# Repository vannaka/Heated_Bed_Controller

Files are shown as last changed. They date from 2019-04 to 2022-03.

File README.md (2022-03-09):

Heated_Bed_Controller

# PCB Images
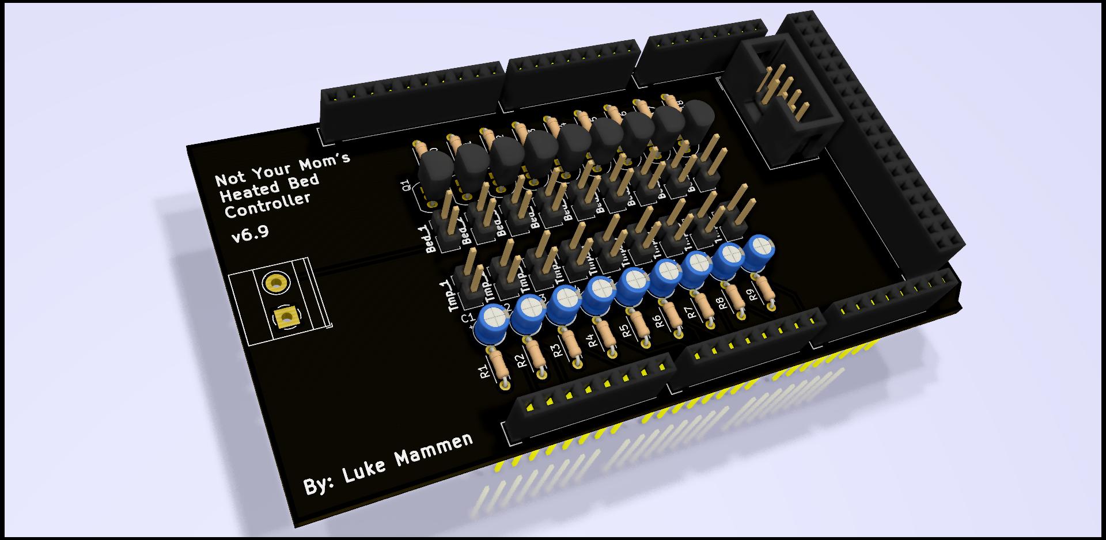
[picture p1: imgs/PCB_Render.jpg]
PCB Render

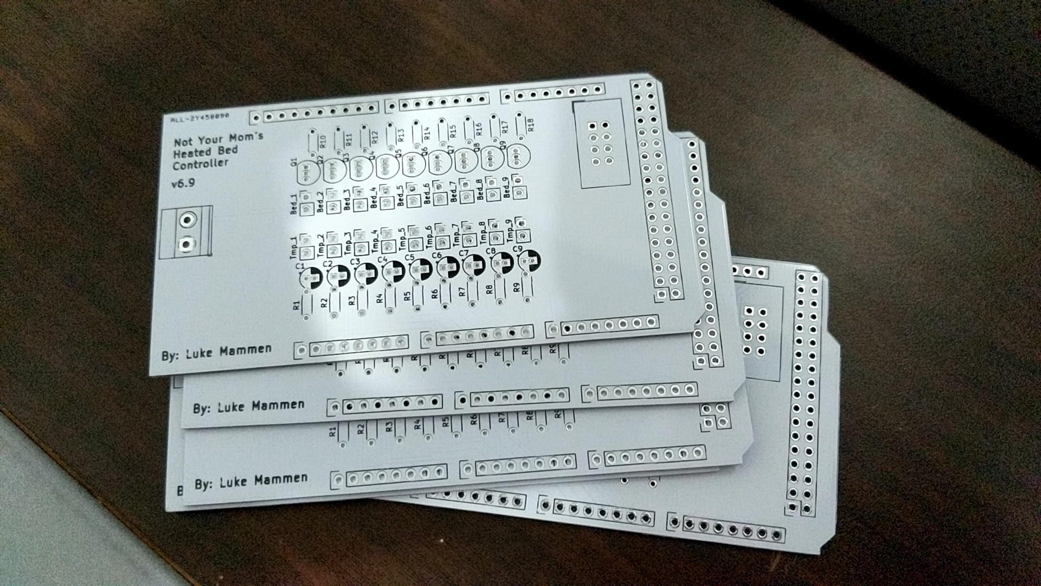
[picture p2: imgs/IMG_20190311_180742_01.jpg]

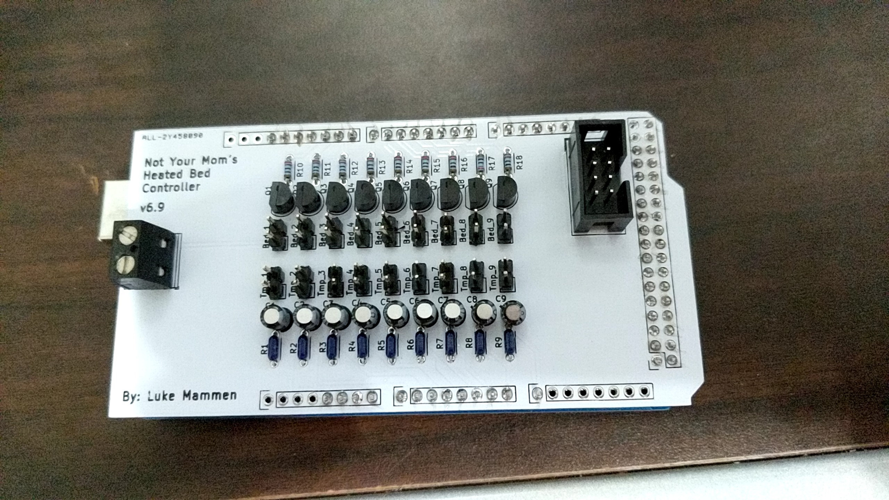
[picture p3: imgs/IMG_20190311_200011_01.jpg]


# Prototyping
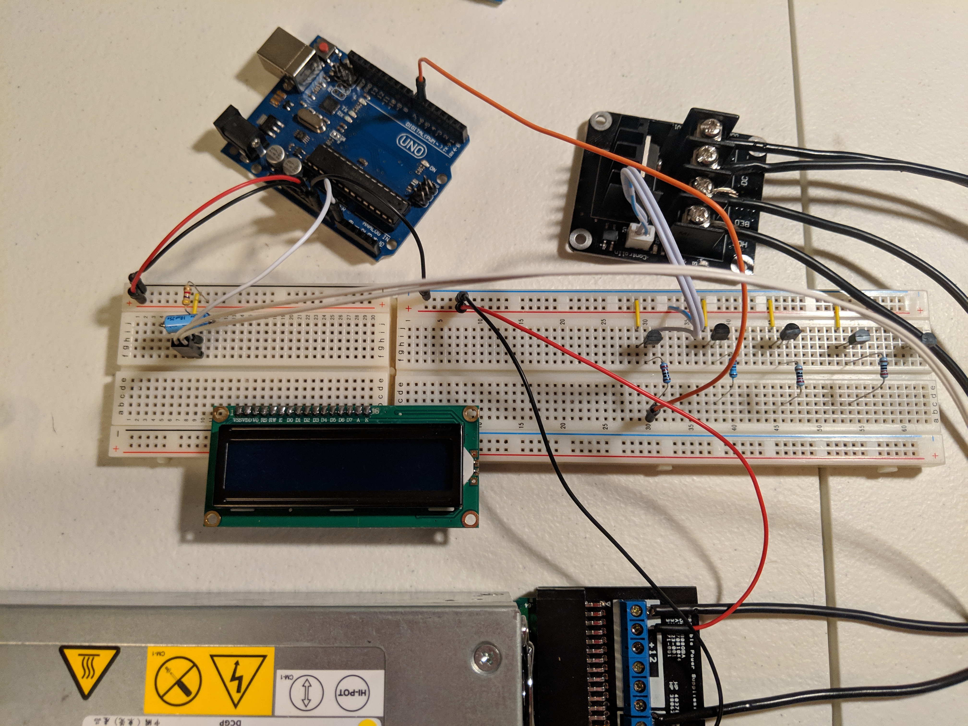
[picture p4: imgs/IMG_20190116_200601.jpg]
Breadboard

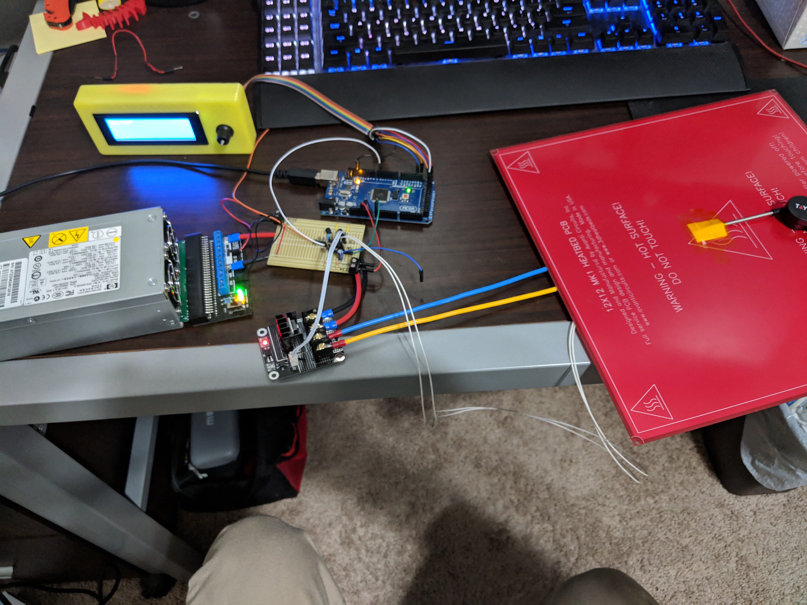
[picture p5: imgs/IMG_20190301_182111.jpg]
Protoboard


# Screen & Nob
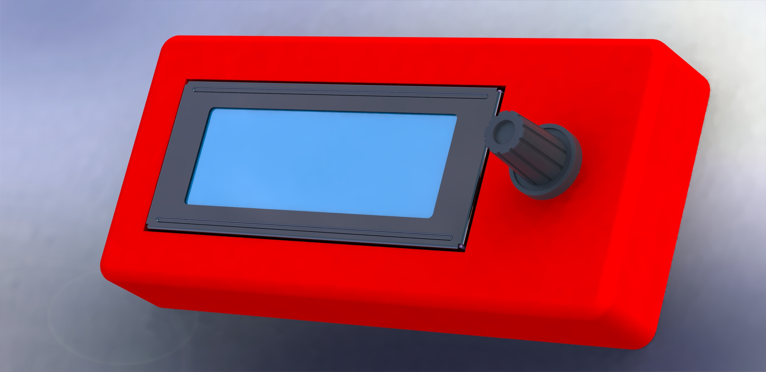
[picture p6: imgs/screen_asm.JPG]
Screen_render

Screen_test
Screen_final

# Wiring
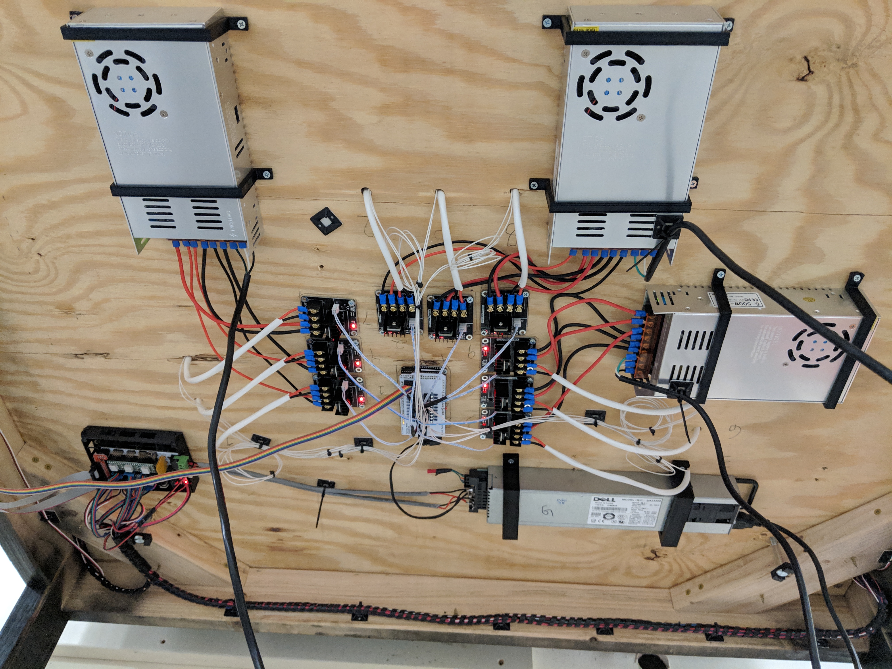
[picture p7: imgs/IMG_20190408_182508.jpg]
Wiring


# Bed & Printer
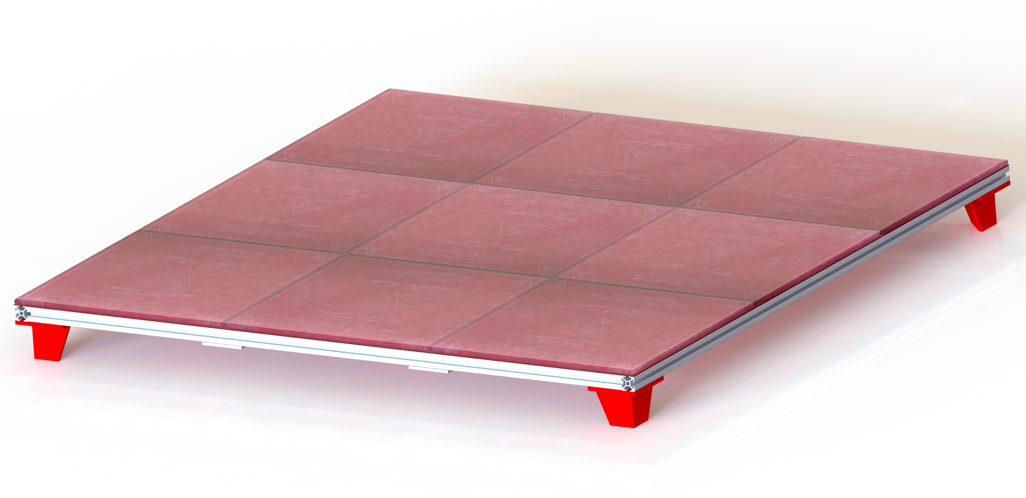
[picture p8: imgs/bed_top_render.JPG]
Bed_render

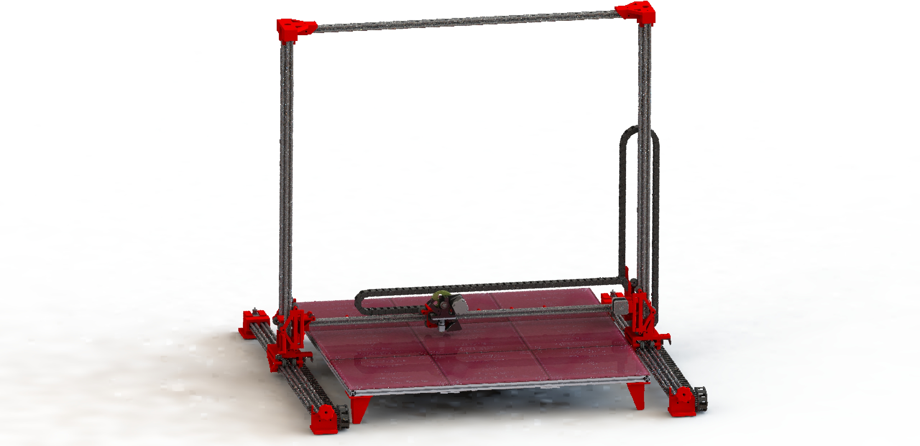
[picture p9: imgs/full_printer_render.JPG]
Full_printer_render

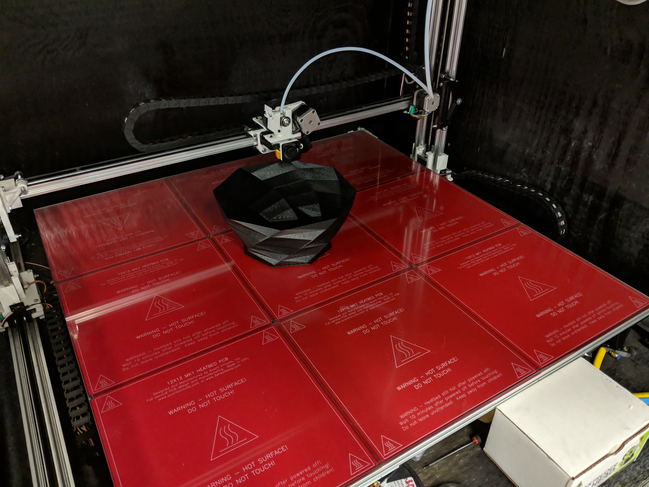
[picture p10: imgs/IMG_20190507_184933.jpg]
vase_mid_print

vase_done

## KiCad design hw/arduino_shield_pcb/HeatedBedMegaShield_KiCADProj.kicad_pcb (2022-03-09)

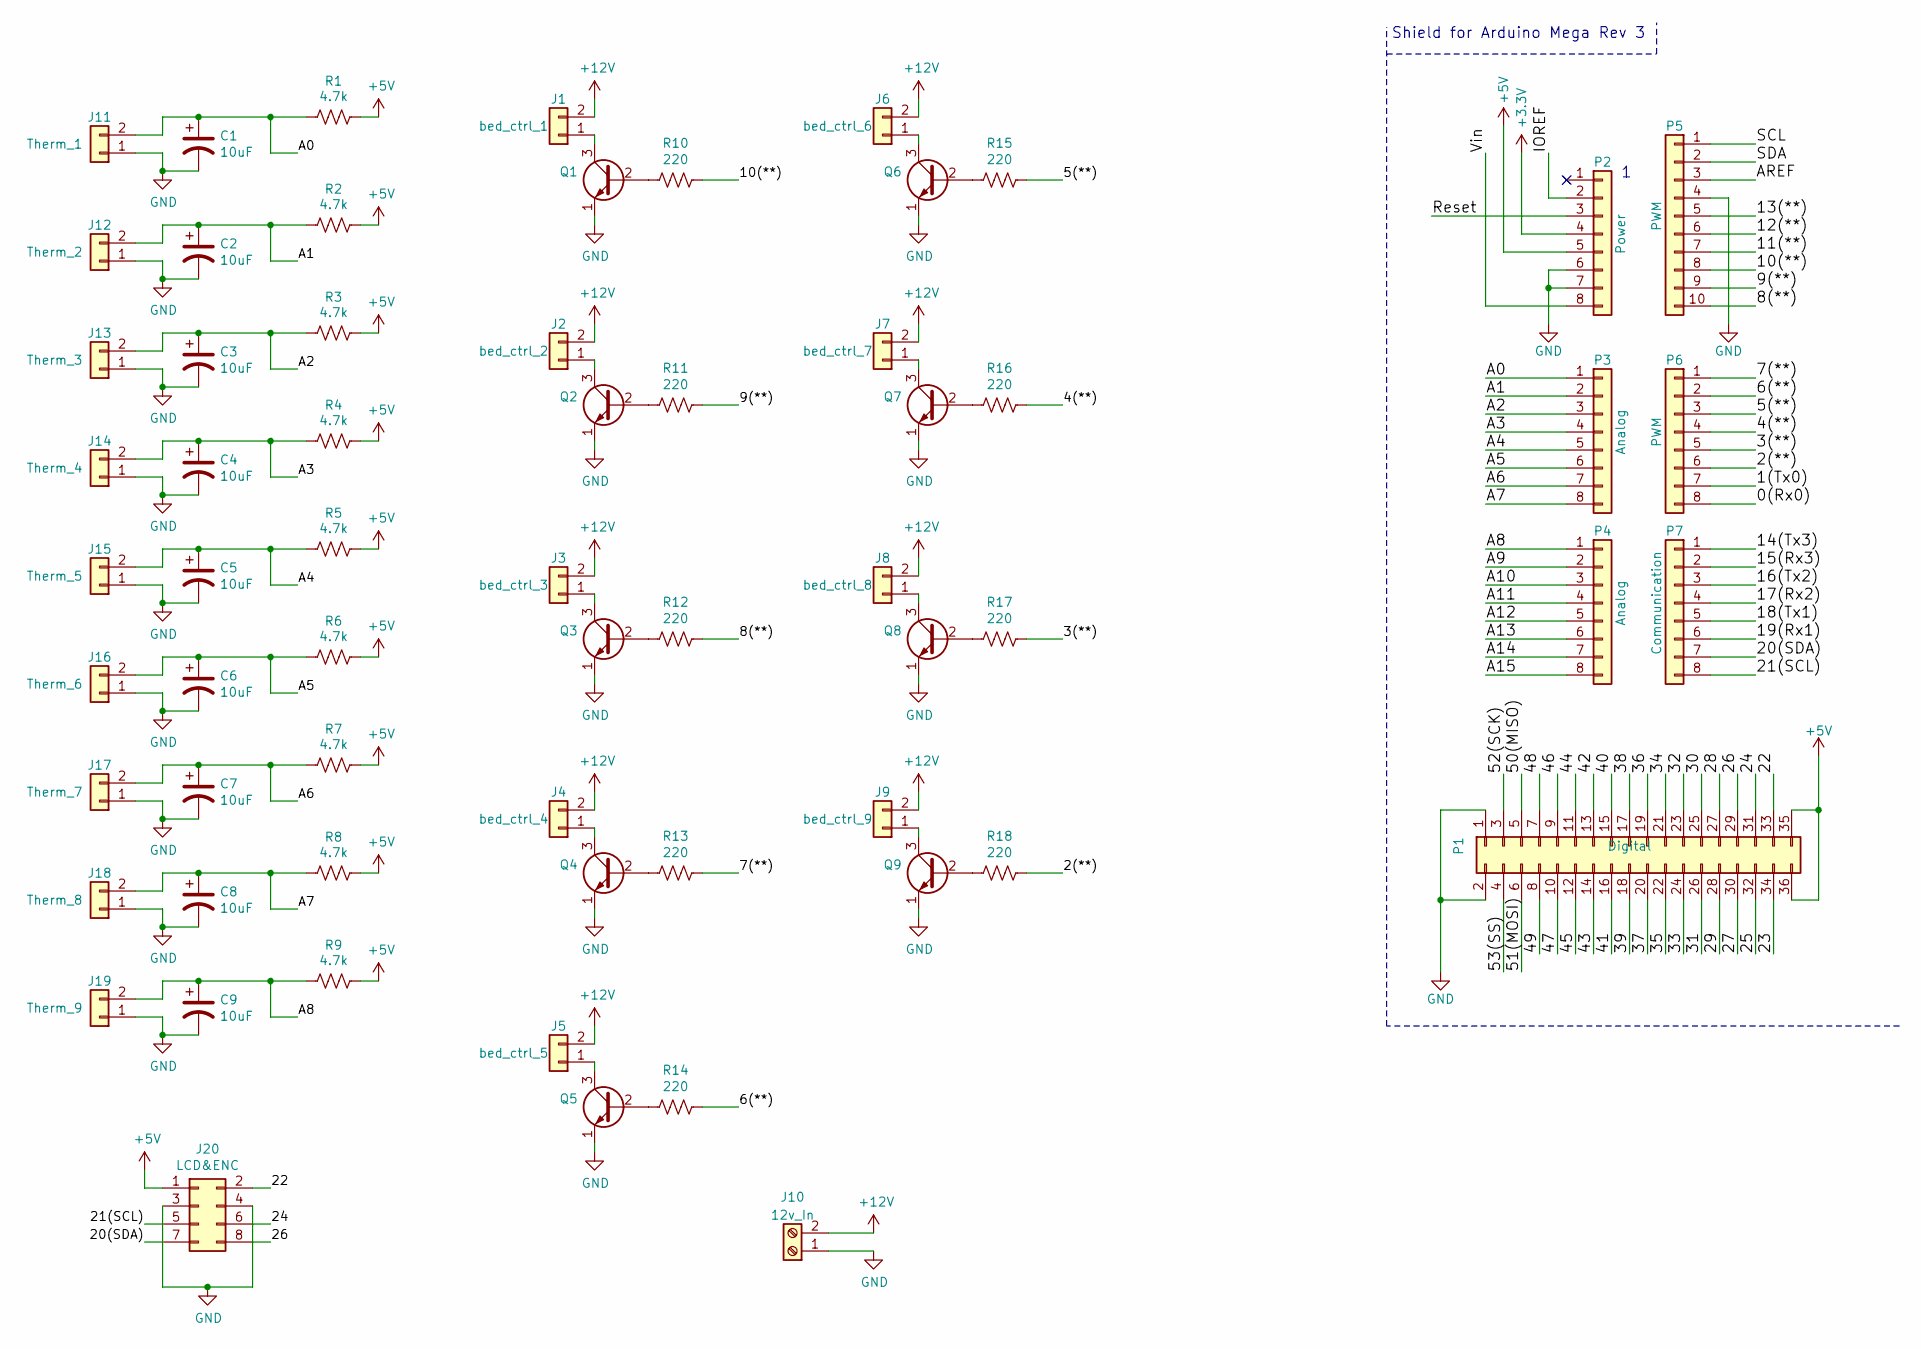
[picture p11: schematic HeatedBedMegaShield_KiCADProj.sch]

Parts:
C1, C2, C3, C4, C5, C6, C7, C8, C9: 10uF; CP_Radial_D4.0mm_P1.50mm
J1: bed_ctrl_1; PinHeader_1x02_P2.54mm_Vertical
J2: bed_ctrl_2; PinHeader_1x02_P2.54mm_Vertical
J3: bed_ctrl_3; PinHeader_1x02_P2.54mm_Vertical
J4: bed_ctrl_4; PinHeader_1x02_P2.54mm_Vertical
J5: bed_ctrl_5; PinHeader_1x02_P2.54mm_Vertical
J6: bed_ctrl_6; PinHeader_1x02_P2.54mm_Vertical
J7: bed_ctrl_7; PinHeader_1x02_P2.54mm_Vertical
J8: bed_ctrl_8; PinHeader_1x02_P2.54mm_Vertical
J9: bed_ctrl_9; PinHeader_1x02_P2.54mm_Vertical
J10: 12v_In; TerminalBlock_Phoenix_MKDS-1,5-2_1x02_P5.00mm_Horizontal
J11: Therm_1; PinHeader_1x02_P2.54mm_Vertical
J12: Therm_2; PinHeader_1x02_P2.54mm_Vertical
J13: Therm_3; PinHeader_1x02_P2.54mm_Vertical
J14: Therm_4; PinHeader_1x02_P2.54mm_Vertical
J15: Therm_5; PinHeader_1x02_P2.54mm_Vertical
J16: Therm_6; PinHeader_1x02_P2.54mm_Vertical
J17: Therm_7; PinHeader_1x02_P2.54mm_Vertical
J18: Therm_8; PinHeader_1x02_P2.54mm_Vertical
J19: Therm_9; PinHeader_1x02_P2.54mm_Vertical
J20: LCD&ENC; IDC-Header_2x04_P2.54mm_Vertical
P1: Digital; Socket_Strip_Arduino_2x18
P2: Power; Socket_Strip_Arduino_1x08
P3, P4: Analog; Socket_Strip_Arduino_1x08
P5: PWM; Socket_Strip_Arduino_1x10
P6: PWM; Socket_Strip_Arduino_1x08
P7: Communication; Socket_Strip_Arduino_1x08
Q1, Q2, Q3, Q4, Q5, Q6, Q7, Q8, Q9: Q_NPN_EBC; TO-92_Inline
R1, R2, R3, R4, R5, R6, R7, R8, R9: 4.7k; R_Axial_DIN0204_L3.6mm_D1.6mm_P5.08mm_Horizontal
R10, R11, R12, R13, R14, R15, R16, R17, R18: 220; R_Axial_DIN0204_L3.6mm_D1.6mm_P5.08mm_Horizontal

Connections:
+3V3: P2.4
+5V: J20.1, P1.35, P1.36, P2.5, R1.1, R2.1, R3.1, R4.1, R5.1, R6.1, R7.1, R8.1, R9.1
+12V: J1.2, J2.2, J3.2, J4.2, J5.2, J6.2, J7.2, J8.2, J9.2, J10.2
/0(Rx0): P6.8
/1(Tx0): P6.7
/2(**): P6.6, R18.1
/3(**): P6.5, R17.1
/4(**): P6.4, R16.1
/5(**): P6.3, R15.1
/6(**): P6.2, R14.1
/7(**): P6.1, R13.1
/8(**): P5.10, R12.1
/9(**): P5.9, R11.1
/10(**): P5.8, R10.1
/11(**): P5.7
/12(**): P5.6
/13(**): P5.5
/14(Tx3): P7.1
/15(Rx3): P7.2
/16(Tx2): P7.3
/17(Rx2): P7.4
/18(Tx1): P7.5
/19(Rx1): P7.6
/20(SDA): J20.7, P7.7
/21(SCL): J20.5, P7.8
/22: J20.2, P1.33
/23: P1.34
/24: J20.6, P1.31
/25: P1.32
/26: J20.8, P1.29
/27: P1.30
/28: P1.27
/29: P1.28
/30: P1.25
/31: P1.26
/32: P1.23
/33: P1.24
/34: P1.21
/35: P1.22
/36: P1.19
/37: P1.20
/38: P1.17
/39: P1.18
/40: P1.15
/41: P1.16
/42: P1.13
/43: P1.14
/44: P1.11
/45: P1.12
/46: P1.9
/47: P1.10
/48: P1.7
/49: P1.8
/50(MISO): P1.5
/51(MOSI): P1.6
/52(SCK): P1.3
/53(SS): P1.4
/A0: C1.1, J11.2, P3.1, R1.2
/A1: C2.1, J12.2, P3.2, R2.2
/A2: C3.1, J13.2, P3.3, R3.2
/A3: C4.1, J14.2, P3.4, R4.2
/A4: C5.1, J15.2, P3.5, R5.2
/A5: C6.1, J16.2, P3.6, R6.2
/A6: C7.1, J17.2, P3.7, R7.2
/A7: C8.1, J18.2, P3.8, R8.2
/A8: C9.1, J19.2, P4.1, R9.2
/A9: P4.2
/A10: P4.3
/A11: P4.4
/A12: P4.5
/A13: P4.6
/A14: P4.7
/A15: P4.8
/AREF: P5.3
/IOREF: P2.2
/Reset: P2.3
/SCL: P5.1
/SDA: P5.2
/Vin: P2.8
GND: C1.2, C2.2, C3.2, C4.2, C5.2, C6.2, C7.2, C8.2, C9.2, J10.1, J11.1, J12.1, J13.1, J14.1, J15.1, J16.1, J17.1, J18.1, J19.1, J20.3, J20.4, P1.1, P1.2, P2.6, P2.7, P5.4, Q1.1 (E), Q2.1 (E), Q3.1 (E), Q4.1 (E), Q5.1 (E), Q6.1 (E), Q7.1 (E), Q8.1 (E), Q9.1 (E)
unnamed: J1.1, Q1.3 (C)
unnamed: J2.1, Q2.3 (C)
unnamed: J3.1, Q3.3 (C)
unnamed: J4.1, Q4.3 (C)
unnamed: J5.1, Q5.3 (C)
unnamed: J6.1, Q6.3 (C)
unnamed: J7.1, Q7.3 (C)
unnamed: J8.1, Q8.3 (C)
unnamed: J9.1, Q9.3 (C)
unnamed: Q1.2 (B), R10.2
unnamed: Q2.2 (B), R11.2
unnamed: Q3.2 (B), R12.2
unnamed: Q4.2 (B), R13.2
unnamed: Q5.2 (B), R14.2
unnamed: Q6.2 (B), R15.2
unnamed: Q7.2 (B), R16.2
unnamed: Q8.2 (B), R17.2
unnamed: Q9.2 (B), R18.2

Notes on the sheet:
Shield for Arduino Mega Rev 3

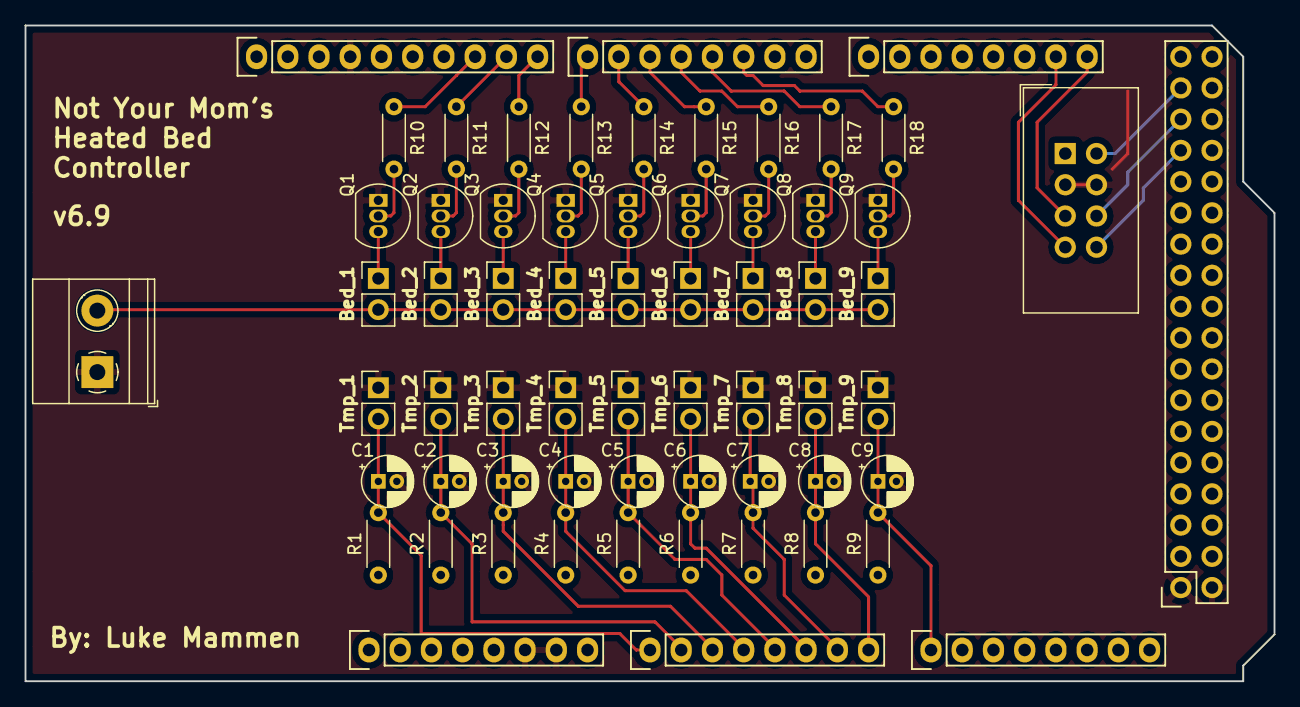
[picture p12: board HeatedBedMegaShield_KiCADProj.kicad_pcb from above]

Board: 2 copper layers, 101.6 x 53.3 mm, 63 parts (0 on the bottom side), 44 nets.

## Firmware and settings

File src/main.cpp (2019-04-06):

#include <Arduino.h>
#include <math.h>

#include <TaskScheduler.h>

#include <Wire.h>
#include <LiquidCrystal_I2C.h>
#include <menu.h>
#include <menuIO/lcdOut.h>
#include <TimerOne.h>
#include <ClickEncoder.h>
#include <menuIO/clickEncoderIn.h>
#include <menuIO/keyIn.h>
#include <menuIO/chainStream.h>
#include <menuIO/serialOut.h>
#include <menuIO/serialIn.h>

#include "heater/heater.h"
#include "pin_defs.h"

#include "softPWM/softpwm.h"

using namespace Menu;
using namespace Palatis;


/******************************************************************************
 *                                 Defines
 *****************************************************************************/
// Encoder
#define encA 22
#define encB 24
#define encBtn 26

// Menu
#define MAX_DEPTH 2

// Beds
#define NUM_BEDS 9

/******************************************************************************
 *                          Function Declarations
 *****************************************************************************/
// Tasks
void bed_task();
void menu_task();

// Menu Callbacks
result displayInfo( menuOut& o, idleEvent e );
result allOff();

/******************************************************************************
 *                               Global Vars
 *****************************************************************************/
// Screen
LiquidCrystal_I2C lcd( 0x27, 2, 1, 0, 4, 5, 6, 7, 3, POSITIVE );
uint8_t degree[8] = { 0xc,0x12,0x12,0xc,0x0,0x0,0x0,0x0 };
uint8_t return_arrow[8] = { 0x4,0xe,0x1f,0x4,0x1c,0x0,0x0,0x0 };

// Encoder
ClickEncoder clickEncoder( encA, encB, encBtn, 4 );
ClickEncoderStream encStream( clickEncoder, 1 );

// Heated bed control vars
float global_temp = 40.0;
float bed_temps[NUM_BEDS] = { 40.0, 40.0, 40.0, 40.0, 40.0, 40.0, 40.0, 40.0, 40.0 };

bool global_on = false;
bool beds_on[NUM_BEDS] = { false };

// Heated beds to control
Heater beds[NUM_BEDS] = 
{
    Heater( HEATER_1_PIN, TEMP_1_PIN ),
    Heater( HEATER_2_PIN, TEMP_2_PIN ),
    Heater( HEATER_3_PIN, TEMP_3_PIN ),
    Heater( HEATER_4_PIN, TEMP_4_PIN ),
    Heater( HEATER_5_PIN, TEMP_5_PIN ),
    Heater( HEATER_6_PIN, TEMP_6_PIN ),
    Heater( HEATER_7_PIN, TEMP_7_PIN ),
    Heater( HEATER_8_PIN, TEMP_8_PIN ),
    Heater( HEATER_9_PIN, TEMP_9_PIN ),
};

// Menu
MENU_INPUTS( in, &encStream );
MENU_OUTPUTS( out, MAX_DEPTH
    ,LCD_OUT( lcd, {0,0,20,4} )
    ,NONE
);

// Toggle menu items
TOGGLE( global_on, globalOnToggle, "Enable: ", doNothing, noEvent, wrapStyle
  ,VALUE( "On", true, doNothing, noEvent )
  ,VALUE( "Off", false, doNothing, noEvent )
);

TOGGLE( beds_on[0], bed1OnToggle, "Enable: ", doNothing, noEvent, wrapStyle
  ,VALUE( "On", true, doNothing, noEvent )
  ,VALUE( "Off", false, doNothing, noEvent )
);

TOGGLE( beds_on[1], bed2OnToggle, "Enable: ", doNothing, noEvent, wrapStyle
  ,VALUE( "On", true, doNothing, noEvent )
  ,VALUE( "Off", false, doNothing, noEvent )
);

TOGGLE( beds_on[2], bed3OnToggle, "Enable: ", doNothing, noEvent, wrapStyle
  ,VALUE( "On", true, doNothing, noEvent )
  ,VALUE( "Off", false, doNothing, noEvent )
);

TOGGLE( beds_on[3], bed4OnToggle, "Enable: ", doNothing, noEvent, wrapStyle
  ,VALUE( "On", true, doNothing, noEvent )
  ,VALUE( "Off", false, doNothing, noEvent )
);

TOGGLE( beds_on[4], bed5OnToggle, "Enable: ", doNothing, noEvent, wrapStyle
  ,VALUE( "On", true, doNothing, noEvent )
  ,VALUE( "Off", false, doNothing, noEvent )
);

TOGGLE( beds_on[5], bed6OnToggle, "Enable: ", doNothing, noEvent, wrapStyle
  ,VALUE( "On", true, doNothing, noEvent )
  ,VALUE( "Off", false, doNothing, noEvent )
);

TOGGLE( beds_on[6], bed7OnToggle, "Enable: ", doNothing, noEvent, wrapStyle
  ,VALUE( "On", true, doNothing, noEvent )
  ,VALUE( "Off", false, doNothing, noEvent )
);

TOGGLE( beds_on[7], bed8OnToggle, "Enable: ", doNothing, noEvent, wrapStyle
  ,VALUE( "On", true, doNothing, noEvent )
  ,VALUE( "Off", false, doNothing, noEvent )
);

TOGGLE( beds_on[8], bed9OnToggle, "Enable: ", doNothing, noEvent, wrapStyle
  ,VALUE( "On", true, doNothing, noEvent )
  ,VALUE( "Off", false, doNothing, noEvent )
);

// Bed Menus
MENU( allBedsMenu, "All Beds          >", doNothing, anyEvent, noStyle
    ,EXIT( "Main              \01" )
    ,FIELD( global_temp,"Global Temp: ","C", 0, 60, 5, 1, doNothing, noEvent, noStyle )
    ,SUBMENU( globalOnToggle )
    ,OP("All Off", allOff, enterEvent)
);

MENU( bed1Menu, "Bed 1             >", doNothing, anyEvent, noStyle
    ,EXIT( "Main              \01" )
    ,FIELD( bed_temps[0], "Bed 1 Temp: ", "C", 0, 60, 5, 1, doNothing, noEvent, noStyle )
    ,SUBMENU( bed1OnToggle )
);

MENU( bed2Menu, "Bed 2             >", doNothing, anyEvent, noStyle
    ,EXIT( "Main              \01" )
    ,FIELD( bed_temps[1], "Bed 2 Temp: ", "C", 0, 60, 5, 1, doNothing, noEvent, noStyle )
    ,SUBMENU( bed2OnToggle )
);

MENU( bed3Menu, "Bed 3             >", doNothing, anyEvent, noStyle
    ,EXIT( "Main              \01" )
    ,FIELD( bed_temps[2], "Bed 3 Temp: ", "C", 0, 60, 5, 1, doNothing, noEvent, noStyle )
    ,SUBMENU( bed3OnToggle )
);

MENU( bed4Menu, "Bed 4             >", doNothing, anyEvent, noStyle
    ,EXIT( "Main              \01" )
    ,FIELD( bed_temps[3], "Bed 4 Temp: ", "C", 0, 60, 5, 1, doNothing, noEvent, noStyle )
    ,SUBMENU( bed4OnToggle )
);

MENU( bed5Menu, "Bed 5             >", doNothing, anyEvent, noStyle
    ,EXIT( "Main              \01" )
    ,FIELD( bed_temps[4], "Bed 5 Temp: ", "C", 0, 60, 5, 1, doNothing, noEvent, noStyle )
    ,SUBMENU( bed5OnToggle )
);

MENU( bed6Menu, "Bed 6             >", doNothing, anyEvent, noStyle
    ,EXIT( "Main              \01" )
    ,FIELD( bed_temps[5], "Bed 6 Temp: ", "C", 0, 60, 5, 1, doNothing, noEvent, noStyle )
    ,SUBMENU( bed6OnToggle )
);

MENU( bed7Menu, "Bed 7             >", doNothing, anyEvent, noStyle
    ,EXIT( "Main              \01" )
    ,FIELD( bed_temps[6], "Bed 7 Temp: ", "C", 0, 60, 5, 1, doNothing, noEvent, noStyle )
    ,SUBMENU( bed7OnToggle )
);

MENU( bed8Menu, "Bed 8             >", doNothing, anyEvent, noStyle
    ,EXIT( "Main              \01" )
    ,FIELD( bed_temps[7], "Bed 8 Temp: ", "C", 0, 60, 5, 1, doNothing, noEvent, noStyle )
    ,SUBMENU( bed8OnToggle )
);

MENU( bed9Menu, "Bed 9             >", doNothing, anyEvent, noStyle
    ,EXIT( "Main              \01" )
    ,FIELD( bed_temps[8], "Bed 9 Temp: ", "C", 0, 60, 5, 1, doNothing, noEvent, noStyle )
    ,SUBMENU( bed9OnToggle )
);

// Main menu
MENU( mainMenu, "Main menu", doNothing, noEvent, noStyle
    ,EXIT( "Info Screen       \01" )
    ,SUBMENU( allBedsMenu )
    ,SUBMENU( bed1Menu )
    ,SUBMENU( bed2Menu )
    ,SUBMENU( bed3Menu )
    ,SUBMENU( bed4Menu )
    ,SUBMENU( bed5Menu )
    ,SUBMENU( bed6Menu )
    ,SUBMENU( bed7Menu )
    ,SUBMENU( bed8Menu )
    ,SUBMENU( bed9Menu )
);

NAVROOT( nav, mainMenu, MAX_DEPTH, in,out );


// Scheduler / Tasks
Scheduler runner;
Task t1( 500, TASK_FOREVER, bed_task );
Task t2( 100, TASK_FOREVER, menu_task );


/******************************************************************************
 *                                 Procedures
 *****************************************************************************/
// Encoder timer
void timerIsr() { clickEncoder.service(); }

void setup()
{
    Serial.begin( 9600 );

    // Setup menu
    nav.timeOut = 10;   // sec
    nav.showTitle = false;
    nav.idleTask = displayInfo;
    nav.exit();         // go to info screen

    // Setup lcd
    lcd.begin( 20,4 );
    lcd.createChar( 1, return_arrow );
    lcd.createChar( 2, degree );

    // Show splash screen
    lcd.setCursor( 0, 0 );
    lcd.print( "Not Your Mom's" );
    lcd.setCursor( 0, 1 );
    lcd.print( "Heated Bed" );
    lcd.setCursor( 0, 3 );
    lcd.print("By: Luke Mammen");
    delay( 5000 );

    // Timer for encoder knob
    Timer1.initialize( 1000 );
    Timer1.attachInterrupt( timerIsr );

    // Heater
    Heater::beginPWM( 15 ); // 15 Hz PWM for heater mosfets

    // Setup cooperative scheduler
    runner.init();
    runner.addTask( t1 );
    runner.addTask( t2 );

    t1.enable();
    t2.enable();
}

void loop() 
{
    runner.execute();
}


/**********************************************************
*   Tasks
**********************************************************/
void bed_task()
{
    for( int i = 0; i < NUM_BEDS; i++ )
    {
        beds[i].setTargetTemp( bed_temps[i] );
        beds[i].enableHeater( beds_on[i] );
        beds[i].update();
    }
}


void menu_task()
{
    nav.poll();
}


/**********************************************************
*   displayInfo
*       Updates the info screen.
**********************************************************/
result displayInfo( menuOut& o, idleEvent e )
{
    static uint32_t old_time = millis();
    uint32_t cur_time = millis();

    if( cur_time - old_time > 500 )
    {
        char screen[81] = {" "};
        screen[80] = '\0';

        for( int i = 0; i < NUM_BEDS; i++ )
        {
            char* entry = screen + ( 20 * ( i / 3 ) ) + ( ( i % 3 ) * 6 );

            float curr_tmp = beds[i].getCurrTemp();
            float trgt_tmp = beds[i].getTargetTemp();

            // Only display target temp if heater is on.
            if( !beds_on[i] )
                trgt_tmp = 0.0;

            // NOTE: the arduino does not support %f modifiers in any
            //  printf varient. We round as a workarount.
            sprintf( entry , "%ld/%ld", round( curr_tmp ), round( trgt_tmp ) );
        }

        // Get rid of null terminators added by sprintf
        for( int i = 0; i < 80; i ++ )
        {
            if( screen[i] == '\0' )
                screen[i] = ' ';
        }

        // For some reason this swaps lines 2 and 3;
        // o.setCursor( 0, 0 );
        // o.print( screen );

        // For whatever reason, the bellow prints the lines
        //  in the correct order while the above swaps 
        //  lines 2 and 3.
        o.setCursor( 0, 0 );
        o.write( screen, 20 );
        o.setCursor( 0, 1 );
        o.write( screen + 20, 20 );
        o.setCursor( 0, 2 );
        o.write( screen + 40, 20 );
        o.setCursor( 0, 3 );
        o.write( screen + 60, 20 );

        old_time += 500;
    }

    nav.idleChanged = true;
    return proceed;
}


/**********************************************************
*   allOff
*       Turn all heaters off.
**********************************************************/
result allOff()
{
    global_on = false;

    for( int i = 0; i < NUM_BEDS; i++ )
    {
        beds_on[ i ] = false;
    }
}

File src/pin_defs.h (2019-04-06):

#ifndef PIN_DEFS_H
#define PIN_DEFS_H

// Coorisponds to SoftPWM channels as defined in heater.cpp
#define HEATER_1_PIN 8
#define HEATER_2_PIN 7
#define HEATER_3_PIN 6
#define HEATER_4_PIN 5
#define HEATER_5_PIN 4
#define HEATER_6_PIN 3
#define HEATER_7_PIN 2
#define HEATER_8_PIN 1
#define HEATER_9_PIN 0

#define TEMP_1_PIN A0
#define TEMP_2_PIN A1
#define TEMP_3_PIN A2
#define TEMP_4_PIN A3
#define TEMP_5_PIN A4
#define TEMP_6_PIN A5
#define TEMP_7_PIN A6
#define TEMP_8_PIN A7
#define TEMP_9_PIN A8


#endif // PIN_DEFS_H

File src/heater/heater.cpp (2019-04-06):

#include <Arduino.h>
#include "heater.h"
#include "temp_table.h"

using namespace Palatis;

/******************************************************************************
 *                                 Defines
 *****************************************************************************/
#define COUNT(a) ( sizeof(a) / sizeof(*a) )

#define PID_CONTROL_RANGE 20
#define Heater_MAX_POWER 150
#define DEAD_TIME 16 // in increments of update()'s period.

#define NUM_SAMPLES 16

// Soft PWM
SOFTPWM_DEFINE_CHANNEL( 0, DDRE, PORTE, PORTE4 );  // Mega pin 2
SOFTPWM_DEFINE_CHANNEL( 1, DDRE, PORTE, PORTE5 );  // Mega pin 3
SOFTPWM_DEFINE_CHANNEL( 2, DDRG, PORTG, PORTG5 );  // Mega pin 4
SOFTPWM_DEFINE_CHANNEL( 3, DDRE, PORTE, PORTE3 );  // Mega pin 5
SOFTPWM_DEFINE_CHANNEL( 4, DDRH, PORTH, PORTH3 );  // Mega pin 6
SOFTPWM_DEFINE_CHANNEL( 5, DDRH, PORTH, PORTH4 );  // Mega pin 7
SOFTPWM_DEFINE_CHANNEL( 6, DDRH, PORTH, PORTH5 );  // Mega pin 8
SOFTPWM_DEFINE_CHANNEL( 7, DDRH, PORTH, PORTH6 );  // Mega pin 9
SOFTPWM_DEFINE_CHANNEL( 8, DDRB, PORTB, PORTB4 );  // Mega pin 10


/******************************************************************************
 *                               Global Vars
 *****************************************************************************/
// Soft PWM
SOFTPWM_DEFINE_OBJECT( 9 );


/******************************************************************************
 *                               Methods
 *****************************************************************************/
Heater::Heater( uint8_t heaterPin, uint8_t tempPin )
{
    this->heaterPin = heaterPin;
    this->tempPin = tempPin;

    pinMode( heaterPin, OUTPUT );
    pinMode( tempPin, INPUT );

    enabled = false;

    targetTemp = 40.0;
    currTemp = 20.0; // Room temp
    deltaTemp = 0.0;
    prevDeltaTemp = 0.0;
    
    heaterPower = 0;
    
    IStateLimitMin = 0;
    IStateLimitMax = Heater_MAX_POWER;
}

void Heater::beginPWM( uint32_t freq )
{
    SoftPWM.begin( freq );
}

void Heater::update()
{
    getTemp();

    if( enabled )
    {
        calcPower();
        setHeaterPower( heaterPower );
    }
    else
    {
        setHeaterPower( 0 );
    }
}

void Heater::setTargetTemp( float temp )
{
    targetTemp = temp;
}

float Heater::getTargetTemp()
{
    return targetTemp;
}

void Heater::getTemp()
{
    float prevTemp;
    int raw = 0;

    // Get raw value from thermistor
    for( int i = 0; i < NUM_SAMPLES; i++ )
    {
        raw += analogRead( tempPin );
    }

    raw = raw >> 2;

    size_t i = 0;
    float celsius = 0;
    
    // Lookup temperature in table
    for( i = 1; i < COUNT( temp_table ); i++ )
    {
        if( temp_table[i][0] > raw )
        {
            celsius = temp_table[i - 1][1] +
                        ( raw - temp_table[i - 1][0] ) *
                        (float)( temp_table[i][1] - temp_table[i - 1][1] ) /
                        (float)( temp_table[i][0] - temp_table[i - 1][0] );
            break;
        }
    }

    // Overflow: Set to last value in the table
    if( i == COUNT( temp_table ) )
    {
        celsius = temp_table[i - 1][1];
    }

    // Update memeber variables
    prevTemp = currTemp;
    currTemp = celsius;

    prevDeltaTemp = deltaTemp;
    deltaTemp = currTemp - prevTemp;
}

int Heater::getPower()
{
    return heaterPower;
}

void Heater::setHeaterPower( int power )
{
    // analogWrite( heaterPin, power );
    SoftPWM.set( heaterPin, power );
}

void Heater::enableHeater( bool enable )
{
    this->enabled = enable;
    // enableTime = millis();
}

float Heater::getCurrTemp()
{
    return currTemp;
}

void Heater::calcPower()
{
    // Local variables
    float error;
    float predictedTemp;

    // Initialize local variables
    error = targetTemp - currTemp;
    predictedTemp = 0.0;

    // Heating off
    if( targetTemp < 20.0 )
    {
        heaterPower = 0;
    }
    // Phase 1: full heating until control range reached
    else if( error > PID_CONTROL_RANGE )
    {
        heaterPower = Heater_MAX_POWER;

        IStateLimitMax = Heater_MAX_POWER;
        IStateLimitMin = 0;
    }
    // Bed is significantly hotter than target temp
    else if( error < -PID_CONTROL_RANGE )
    {
        heaterPower = 0;
    }
    // control range handle by heat manager
    else
    {
        // Peak reached
        if( prevDeltaTemp >= 0 && deltaTemp < 0 )
        {
            if( error < -0.5 )
            {
                IStateLimitMax = constrain( IStateLimitMax - 10, IStateLimitMin, Heater_MAX_POWER );
            }
            else
            {
                IStateLimitMax = constrain( IStateLimitMax + 10, IStateLimitMin, Heater_MAX_POWER );
            }
        }
        // Bottom reached
        else if( prevDeltaTemp <= 0 && deltaTemp > 0 )
        {
            if( error > 0.5 )
            {
                IStateLimitMin = constrain( IStateLimitMin + 10, 0, IStateLimitMax - 20 );
            }
            else
            {
                IStateLimitMin = constrain( IStateLimitMin - 10, 0, IStateLimitMax - 20 );
            }
        }

        // Calculate the temp after the dead time
        predictedTemp = currTemp + deltaTemp * DEAD_TIME;

        heaterPower = predictedTemp > targetTemp ? IStateLimitMin : IStateLimitMax;
    }
}

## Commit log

2019-02-16 Switch to ArduinoMenu library for menu's.
2019-03-04 Increase adc samples
2019-03-13 Use arrays for vars related to heated beds
2019-04-06 The heaters now use software pwm to allow variable frequency.
2022-03-09 Add KiCAD files for arduino shield pcb.
    [HeatedBedMegaShield_KiCADProj.kicad_pcb, HeatedBedMegaShield_KiCADProj.sch]
